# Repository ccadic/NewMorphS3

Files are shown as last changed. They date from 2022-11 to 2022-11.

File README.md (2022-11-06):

# NewMorphS3
New ESP32S3 dev board from Morpheans.com 

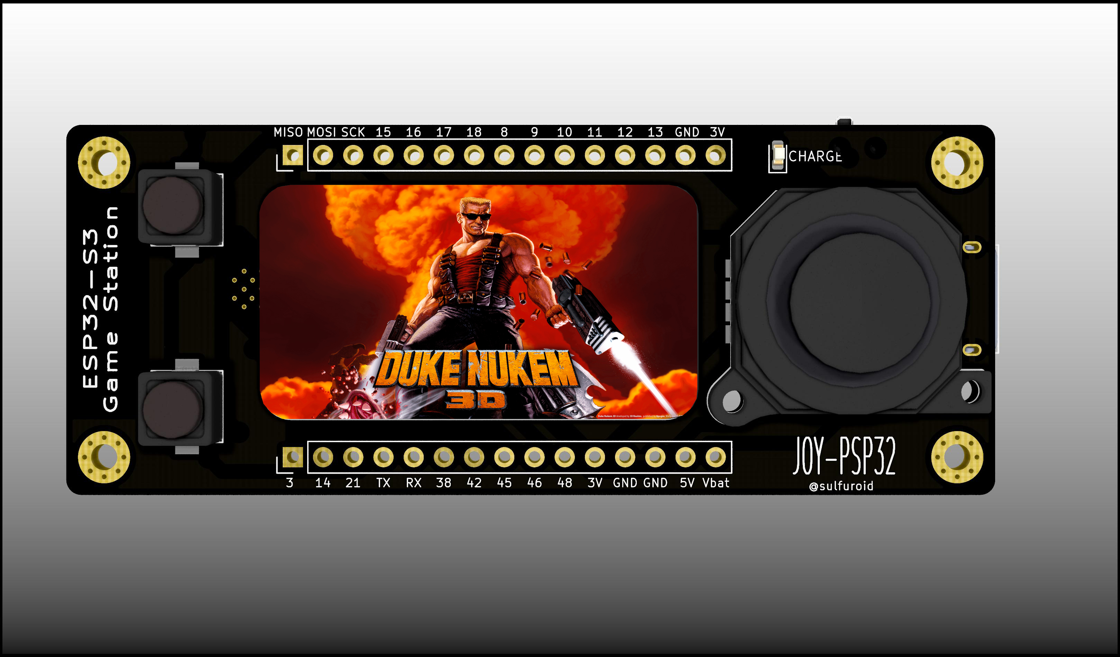
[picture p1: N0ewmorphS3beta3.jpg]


PSP32-S3 game station version 2:  display position modified + I2S sound added + accelerometer added + uSD Card added - Still USB-C, Battery , Charger, ON/OFF Slider switch , PSP joystick and 2 buttons. 

From @sulfuroid

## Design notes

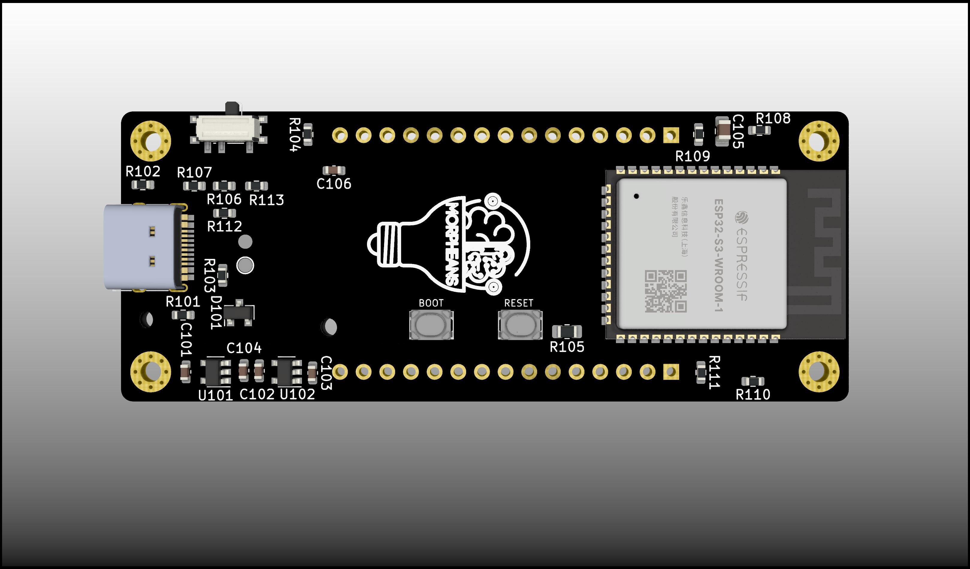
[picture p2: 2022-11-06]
NewmorphS3D.jpg

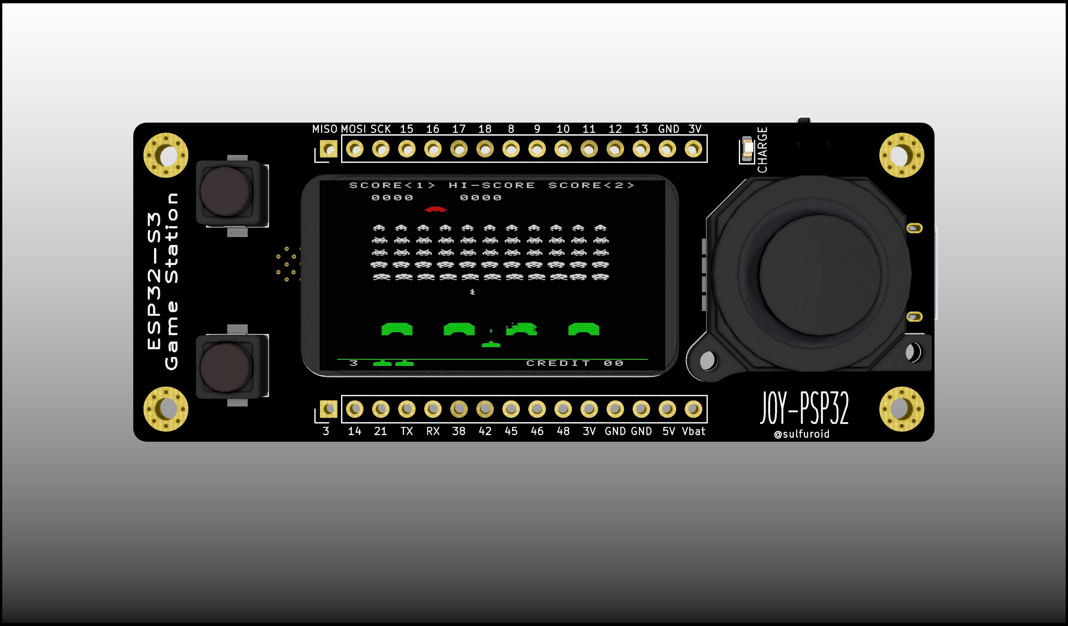
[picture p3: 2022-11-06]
NewmorphS3E.jpg

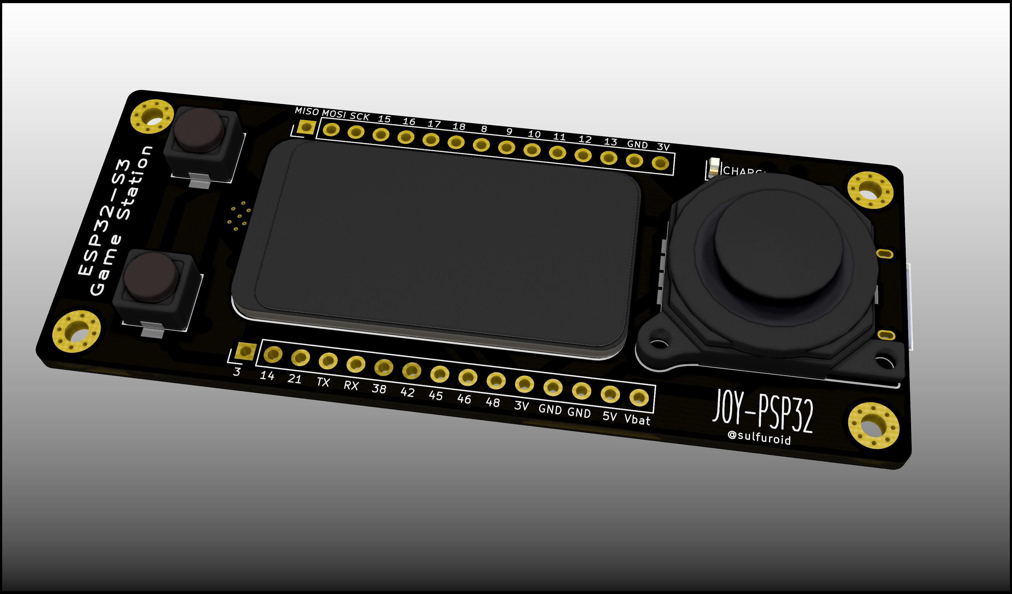
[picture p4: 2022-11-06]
NewmorphS3beta2.jpg

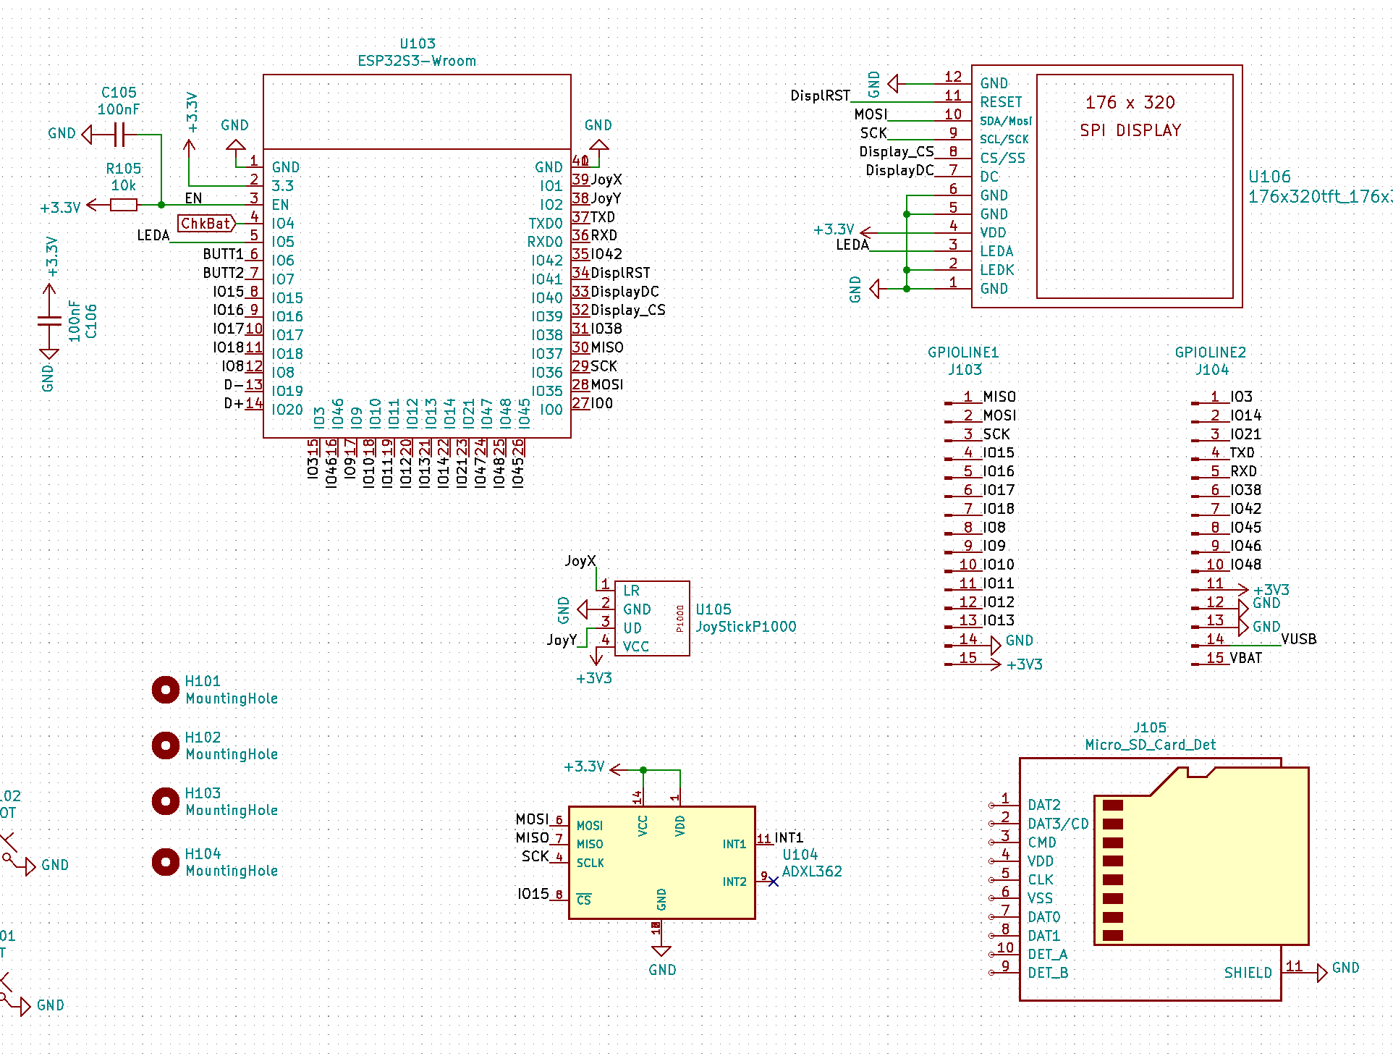
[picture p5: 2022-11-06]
partial.jpg

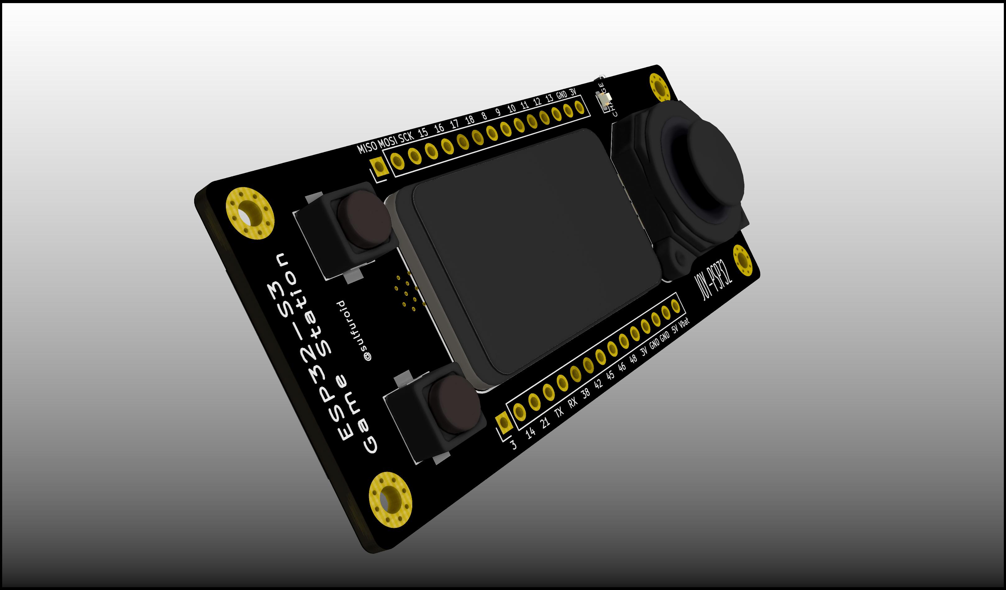
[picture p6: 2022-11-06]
NewmorphS3.bjpg.jpg

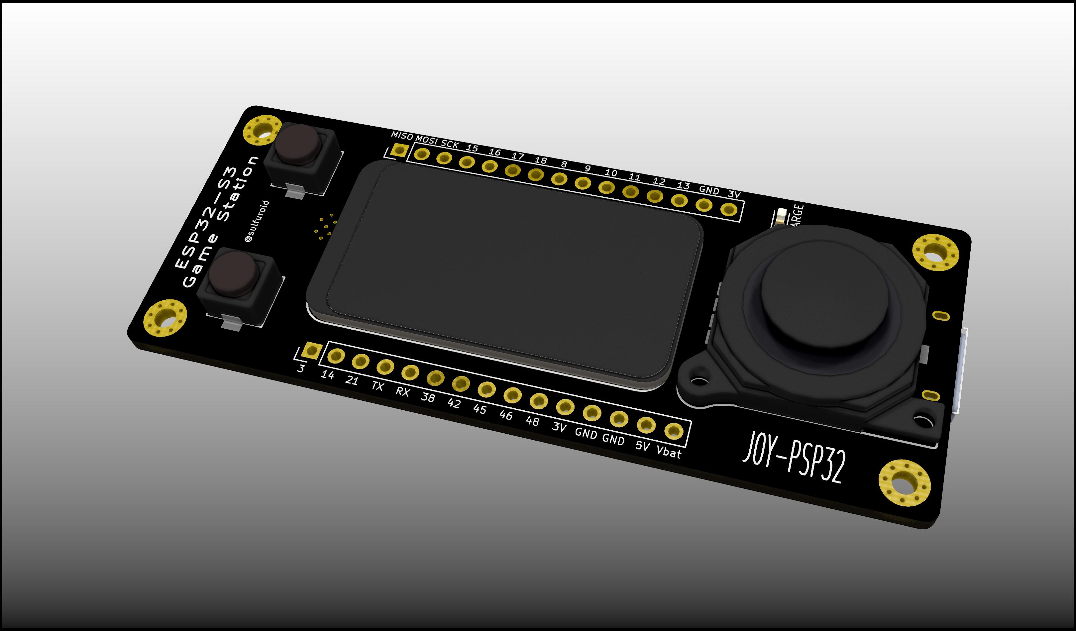
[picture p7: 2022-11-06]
NewmorphS3.jpg

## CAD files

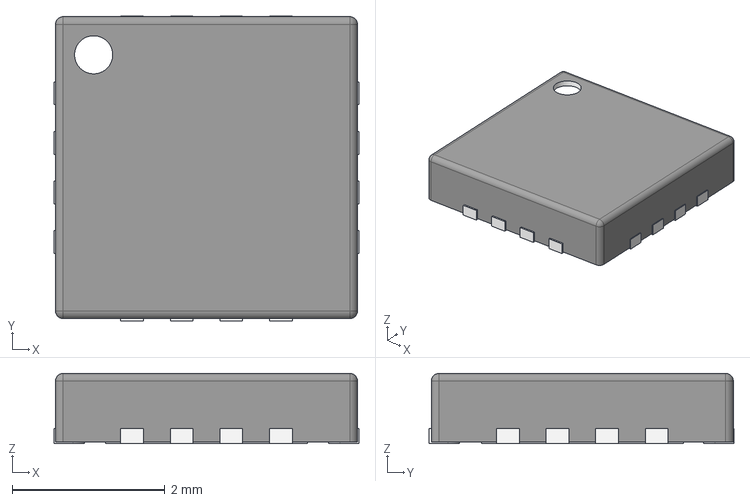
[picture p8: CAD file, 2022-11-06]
QFN-16 (4x4x0.9).step
4.00 x 4.00 x 0.92 mm

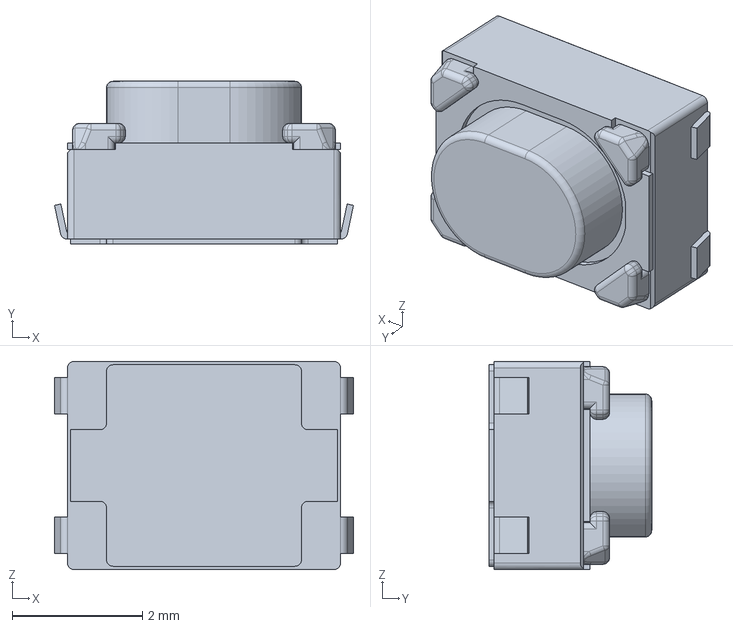
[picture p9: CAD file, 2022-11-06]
SKRPABE010.step
4.60 x 2.50 x 3.20 mm

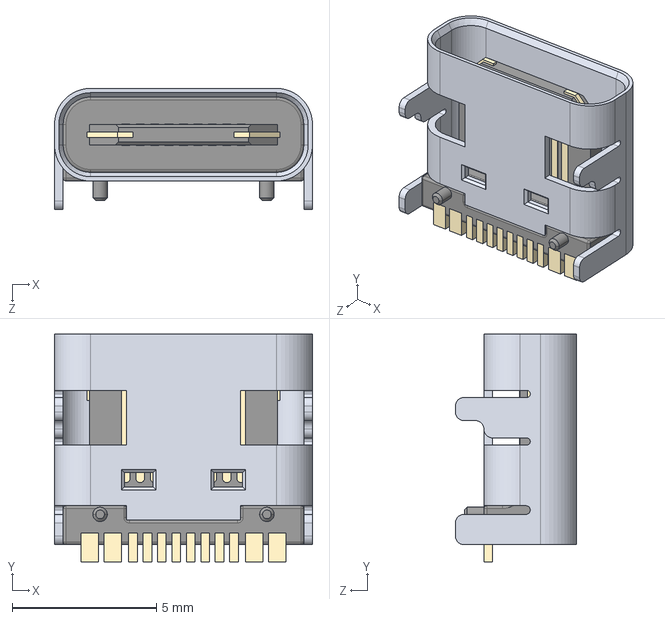
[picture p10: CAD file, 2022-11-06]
USB Type C Port (SMD Type).STEP
8.94 x 7.90 x 4.20 mm

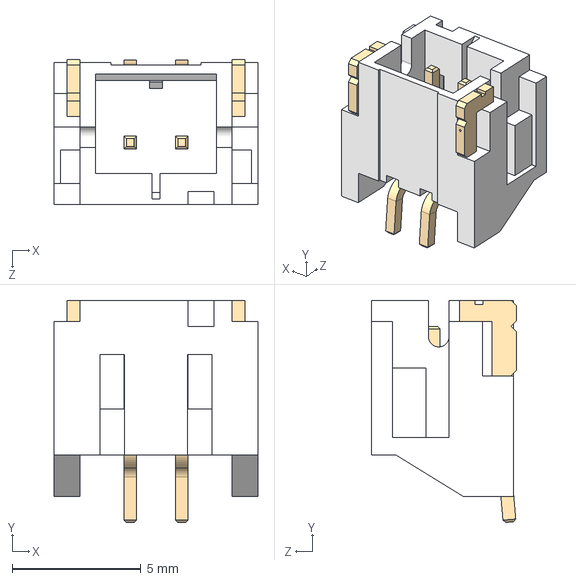
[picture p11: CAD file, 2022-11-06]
JST-S2B-PH-SM4-TB.STEP
7.90 x 8.61 x 5.61 mm

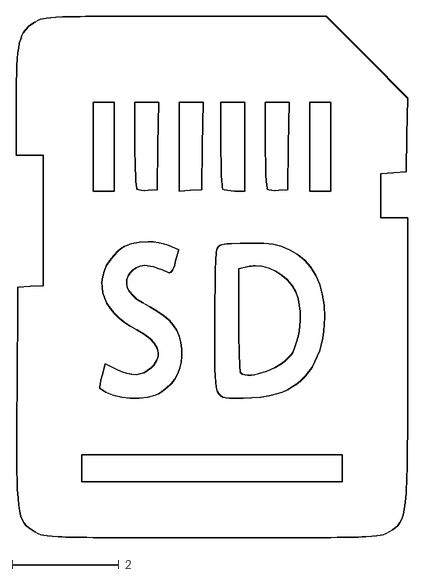
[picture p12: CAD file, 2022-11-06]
microsd.dxf
7.32 x 9.76

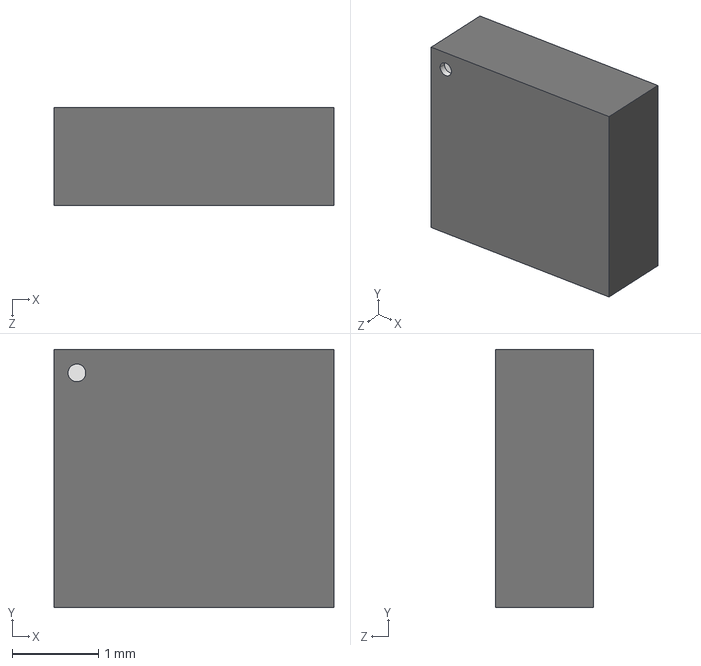
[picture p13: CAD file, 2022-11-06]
ADXL362.STEP
3.25 x 3.00 x 1.14 mm

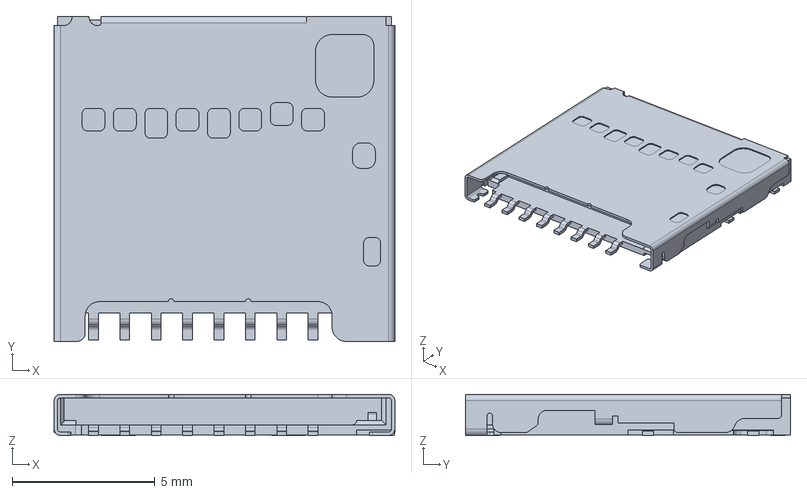
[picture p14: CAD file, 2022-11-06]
1040310811.stp
11.9 x 11.4 x 1.45 mm

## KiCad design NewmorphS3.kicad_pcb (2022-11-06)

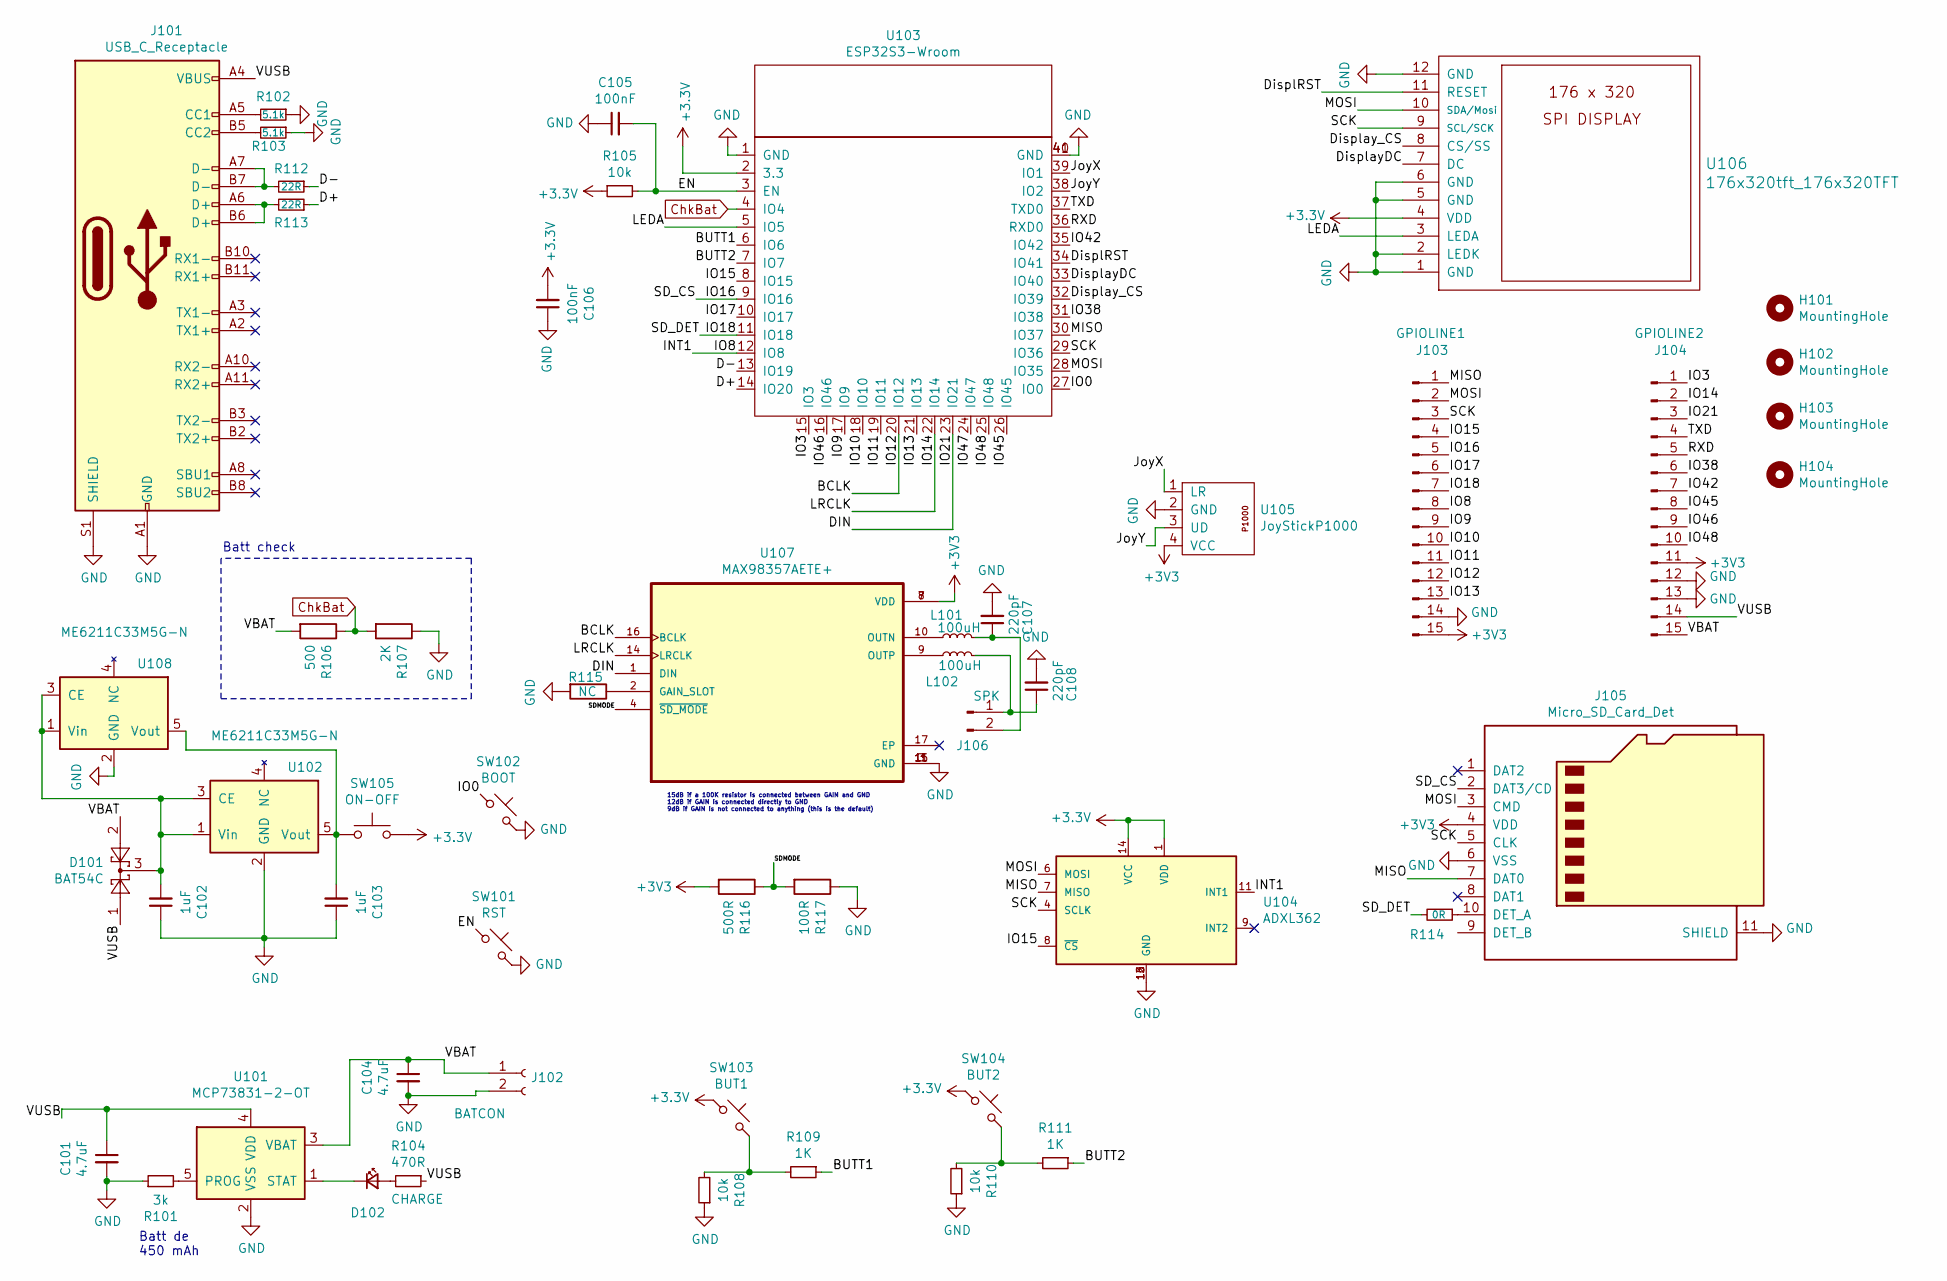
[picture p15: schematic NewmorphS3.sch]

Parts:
C101, C104: 4.7uF; C_0603_1608Metric
C102, C103: 1uF; C_0603_1608Metric
C105: 100nF; C_0805_2012Metric_Pad1.18x1.45mm_HandSolder
C106: 100nF; C_0603_1608Metric
C107, C108: 220pF; C_0603_1608Metric
D101: BAT54C; SOT-23
D102: CHARGE; LED_0603_1608Metric
H101, H102, H103, H104: MountingHole; MountingHole_2.2mm_M2_Pad_Via
J101: USB_C_Receptacle; GT-USB-7010
J102: BATCON; JST_PH_S2B-PH-SM4-TB_1x02-1MP_P2.00mm_Horizontal
J103: GPIOLINE1; PinHeader_1x15_P2.54mm_Vertical
J104: GPIOLINE2; PinHeader_1x15_P2.54mm_Vertical
J105: Micro_SD_Card_Det; microSD_HC_Molex_104031-0811
J106: SPK; 2pads
L101, L102: 100uH; L_0805_2012Metric
R101: 3k; R_0603_1608Metric
R102, R103: 5.1k; R_0603_1608Metric
R104: 470R; R_0603_1608Metric
R105: 10k; R_0805_2012Metric_Pad1.20x1.40mm_HandSolder
R106: 500; R_0603_1608Metric
R107: 2K; R_0603_1608Metric
R108, R110: 10k; R_0603_1608Metric
R109, R111: 1K; R_0603_1608Metric
R112, R113: 22R; R_0603_1608Metric
R114: 0R; R_0603_1608Metric
R115: NC; R_0603_1608Metric
R116: 500R; R_0603_1608Metric
R117: 100R; R_0603_1608Metric
SW101: RST; SKRPABE010
SW102: BOOT; SKRPABE010
SW103: BUT1; SW_TP1003
SW104: BUT2; SW_TP1003
SW105: ON-OFF; SW_SPDT_PCM12
U101: MCP73831-2-OT; SOT-23-5
U102, U108: ME6211C33M5G-N; SOT-23-5
U103: ESP32S3-Wroom; ESP32-S3-wrooom
U104: ADXL362; DIGIKEY ADXL362BCCZ-RL7CT-ND
U105: JoyStickP1000; JoystickP1000
U106: 176x320tft_176x320TFT; ST7789-176x320
U107: MAX98357AETE+; QFN50P300X300X80-17N

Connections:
/BCLK: J103.12, U103.20 (IO12), U107.16 (BCLK)
/BUTT1: R109.1, U103.6 (IO6)
/BUTT2: R111.1, U103.7 (IO7)
/D+: R113.1, U103.14 (IO20)
/D-: R112.1, U103.13 (IO19)
/DIN: J104.3, U103.23 (IO21), U107.1 (DIN)
/DisplRST: U103.34 (IO41), U106.11 (RESET)
/DisplayDC: U103.33 (IO40), U106.7 (DC)
/Display_CS: U103.32 (IO39), U106.8 (CS/SS)
/EN: C105.2, R105.2, SW101.1, U103.3 (EN)
/INT1: J103.8, U103.12 (IO8), U104.11 (INT1)
/IO0: SW102.1, U103.27 (IO0)
/IO3: J104.1, U103.15 (IO3)
/IO9: J103.9, U103.17 (IO9)
/IO10: J103.10, U103.18 (IO10)
/IO11: J103.11, U103.19 (IO11)
/IO13: J103.13, U103.21 (IO13)
/IO14: J104.2, U103.22 (IO14), U107.14 (LRCLK)
/IO15: J103.4, U103.8 (IO15), U104.8 (~CS)
/IO16: J103.5, J105.2 (DAT3/CD), U103.9 (IO16)
/IO17: J103.6, U103.10 (IO17)
/IO18: J103.7, R114.2, U103.11 (IO18)
/IO38: J104.6, U103.31 (IO38)
/IO42: J104.7, U103.35 (IO42)
/IO45: J104.8, U103.26 (IO45)
/IO46: J104.9, U103.16 (IO46)
/IO48: J104.10, U103.25 (IO48)
/JoyX: U103.39 (IO1), U105.1 (LR)
/JoyY: U103.38 (IO2), U105.3 (UD)
/LEDA: U103.5 (IO5), U106.3 (LEDA)
/MISO: J103.1, J105.7 (DAT0), U103.30 (IO37), U104.7 (MISO)
/MOSI: J103.2, J105.3 (CMD), U103.28 (IO35), U104.6 (MOSI), U106.10 (SDA/Mosi)
/RXD: J104.5, U103.36 (RXD0)
/SCK: J103.3, J105.5 (CLK), U103.29 (IO36), U104.4 (SCLK), U106.9 (SCL/SCK)
/SDMODE: R116.1, R117.2, U107.4 (~SD_MODE)
/TXD: J104.4, U103.37 (TXD0)
/VBAT: C104.1, D101.2, J102.1, J104.15, R106.2, U101.3 (VBAT)
/VUSB: C101.1, D101.1, J101.A4 (VBUS), J101.A9 (VBUS), J101.B4 (VBUS), J101.B9 (VBUS), J104.14, R104.1, U101.4 (VDD)
ChkBat: R106.1, R107.2, U103.4 (IO4)
GND: C101.2, C102.1, C103.1, C104.2, C105.1, C106.1, C107.2, C108.2, J101.A1 (GND), J101.A12 (GND), J101.B1 (GND), J101.B12 (GND), J101.S1 (SHIELD), J102.2, J103.14, J104.12, J104.13, J105.6 (VSS), J105.11 (SHIELD), R101.1, R102.1, R103.1, R107.1, R108.1, R110.1, R115.2, R117.1, SW101.2, SW102.2, U101.2 (VSS), U102.2 (GND), U103.1 (GND), U103.40 (GND), U103.41 (GND), U104.12 (GND), U104.13 (GND), U104.16 (GND), U105.2 (GND), U106.1 (GND), U106.2 (LEDK), U106.5 (GND), U106.6 (GND), U106.12 (GND), U107.3 (GND), U107.11 (GND), U107.15 (GND), U108.2 (GND)
unnamed: C102.2, D101.3, U102.1 (Vin), U102.3 (CE), U108.1 (Vin), U108.3 (CE)
unnamed: C103.2, SW105.1, U102.5 (Vout), U108.5 (Vout)
unnamed: C107.1, J106.2, L101.2
unnamed: C108.1, J106.1, L102.2
unnamed: D102.1 (K), U101.1 (STAT)
unnamed: D102.2 (A), R104.2
unnamed: J101.A5 (CC1), R102.2
unnamed: J101.A6 (D+), J101.B6 (D+), R113.2
unnamed: J101.A7 (D-), J101.B7 (D-), R112.2
unnamed: J101.B5 (CC2), R103.2
unnamed: J105.10 (DET_A), R114.1
unnamed: L101.1, U107.10 (OUTN)
unnamed: L102.1, U107.9 (OUTP)
unnamed: R101.2, U101.5 (PROG)
unnamed: R108.2, R109.2, SW103.2
unnamed: R110.2, R111.2, SW104.2
unnamed: R115.1, U107.2 (GAIN_SLOT)

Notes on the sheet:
Batt de 450 mAh
Batt check
15dB if a 100K resistor is connected between GAIN and GND 12dB if GAIN is connected directly to GND 9dB if GAIN is not connected to anything (this is the default)

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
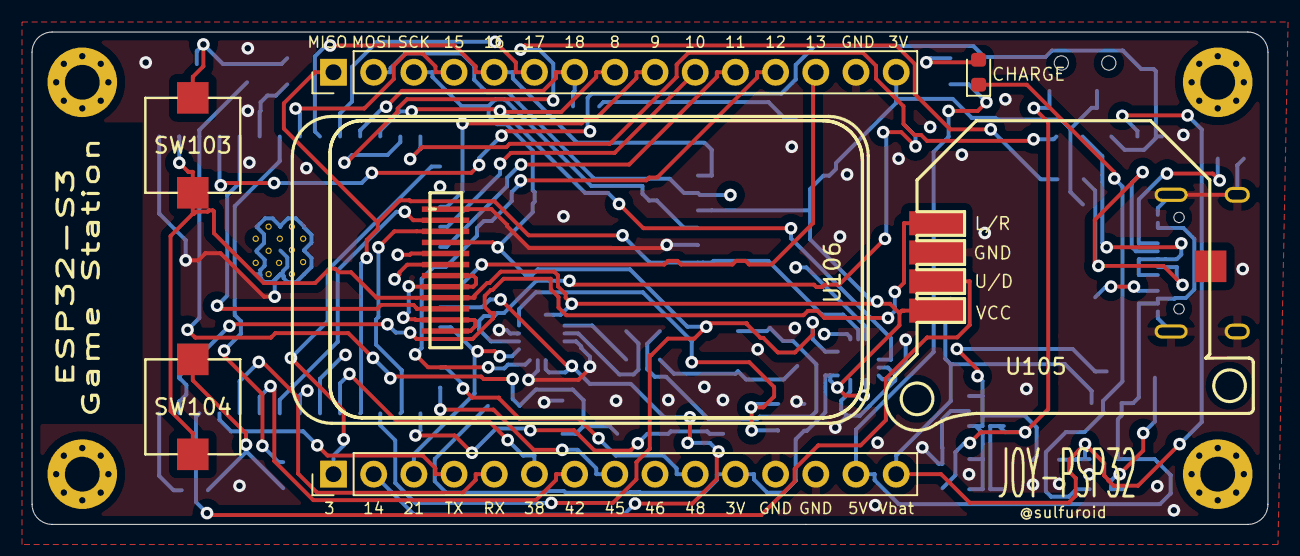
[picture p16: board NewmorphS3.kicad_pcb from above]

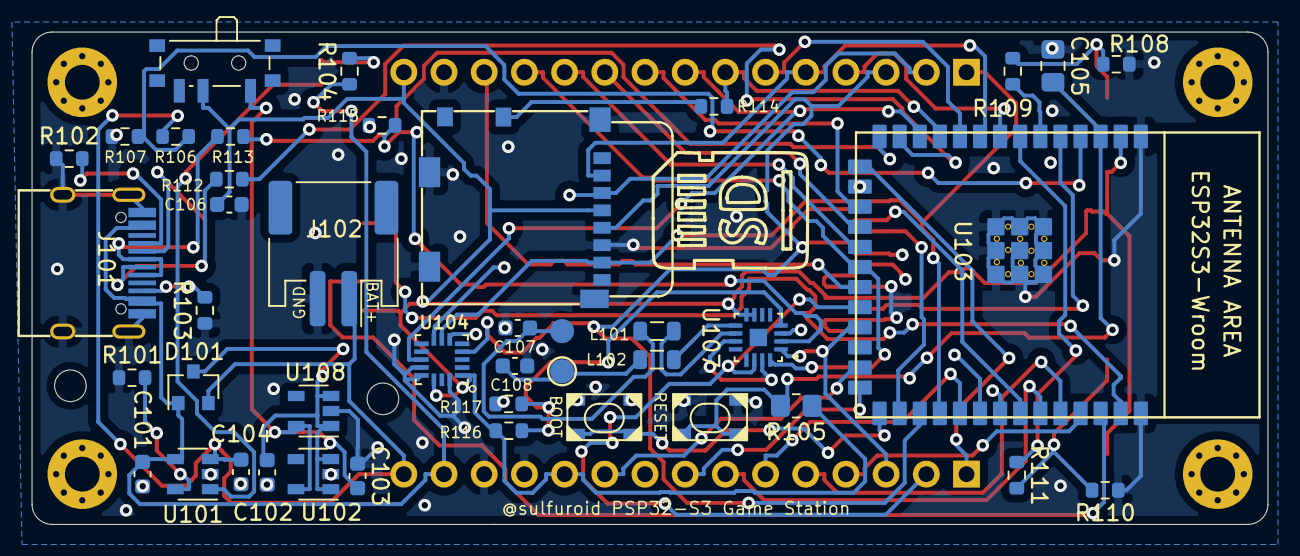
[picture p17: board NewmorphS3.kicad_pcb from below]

Board: 4 copper layers, 78.1 x 31.1 mm, 52 parts (41 on the bottom side), 58 nets.
